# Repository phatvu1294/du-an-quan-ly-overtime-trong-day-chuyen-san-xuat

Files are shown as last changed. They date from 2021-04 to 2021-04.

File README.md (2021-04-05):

# Dự án quản lý overtime trong dây truyền sản xuất
*Dự án quản lý overtime trong dây truyền sản xuất được phát triển trên LoRa, ESP32, Arduino và C# Winform*

### Giới thiệu
Đây là bản demo cho hệ thống quản lý overtime trong dây chuyền sản xuất để đánh giá hiệu quả công việc của từng line sản xuất.
Bản demo được thiết kế trên EAGLE với mạch một lớp, không tối ưu cho bảng mạch, để áp dụng trong thương mại vui lòng liên hệ tác giả.

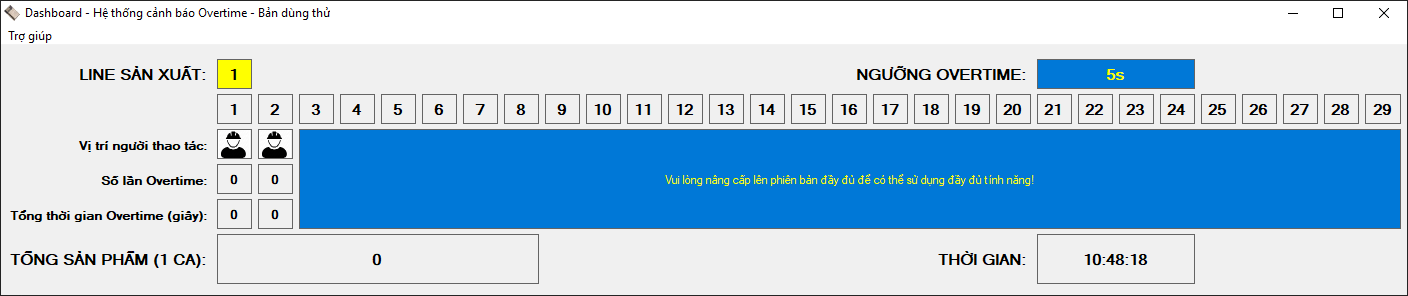
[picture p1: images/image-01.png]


### Mô tả hệ thống

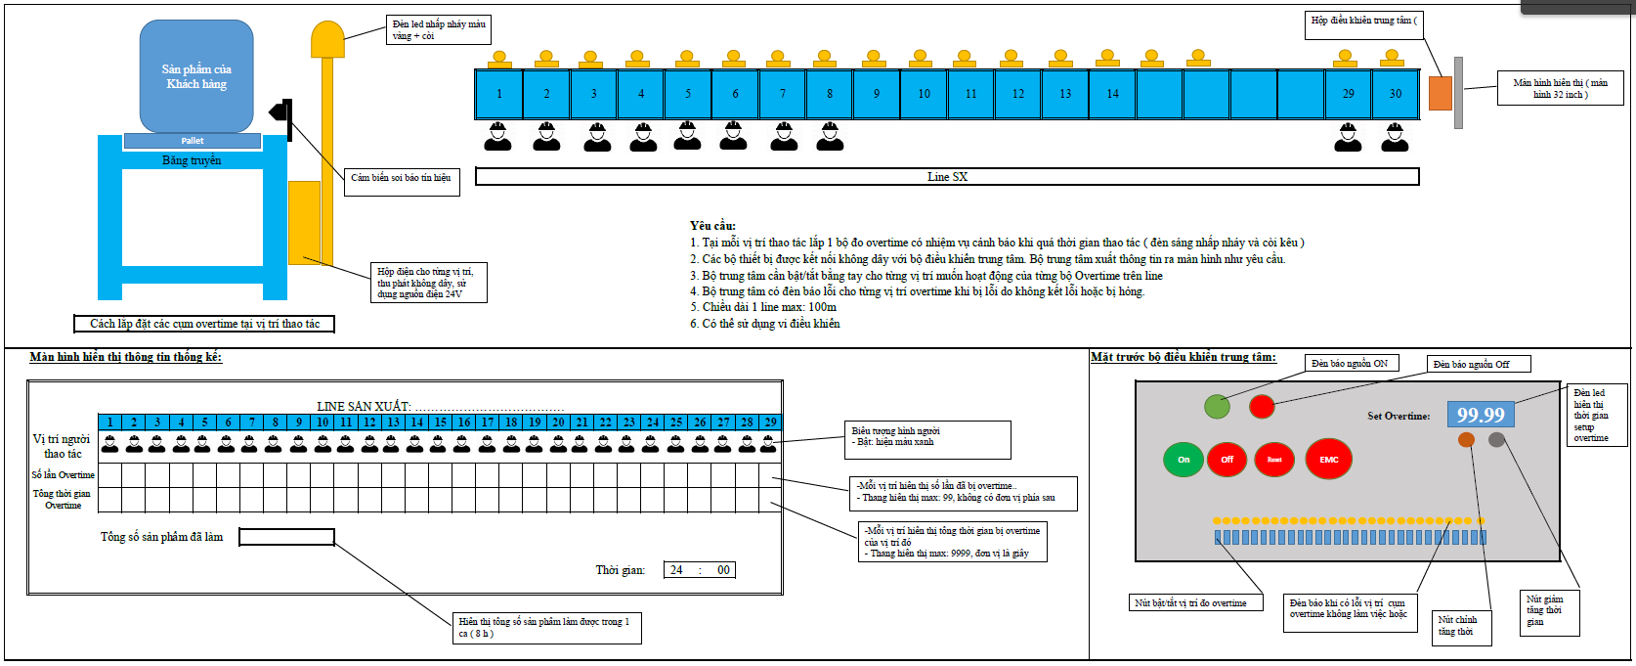
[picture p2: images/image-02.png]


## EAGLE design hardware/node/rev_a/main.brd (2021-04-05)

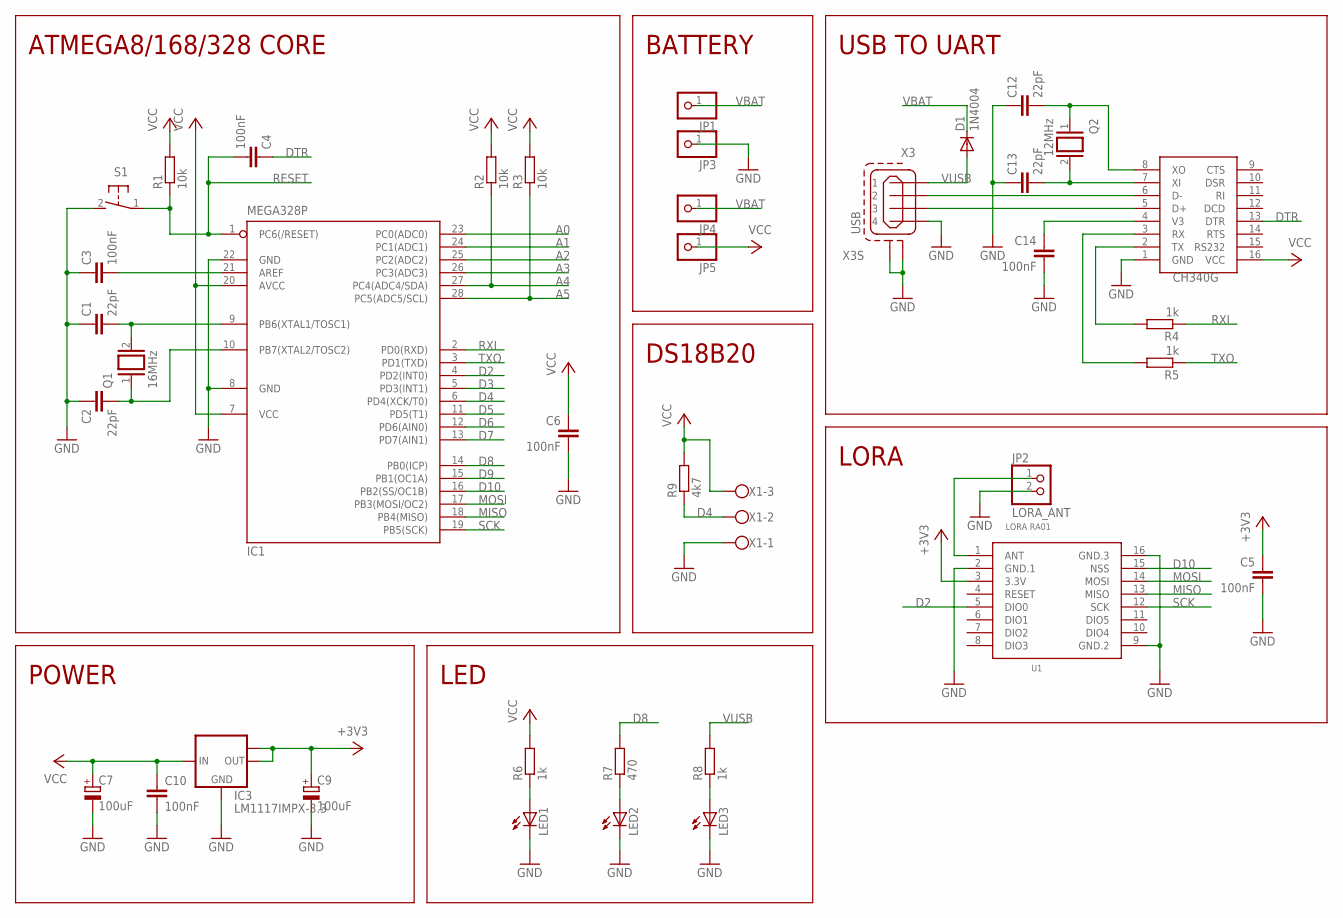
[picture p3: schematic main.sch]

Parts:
C1, C2, C12, C13: 22pF; C050-024X044
C3, C4, C5, C6, C10, C14: 100nF; C050-024X044
C7: 100uF; E3,5-10
C9: 100uF; E3,5-8
D1: 1N4004; DO41-10
IC1: MEGA328P; DIL28-3
IC3: LM1117IMPX-3.3; SOT223
JP1, JP3, JP4, JP5: PINHD-1X1; 1X01
JP2: LORA_ANT; 1X02
LED1, LED2, LED3: LED3MM
Q1: 16MHz; QS
Q2: 12MHz; QS
R1, R2, R3: 10k; 0207/10
R4, R5, R6, R8: 1k; 0207/10
R7: 470; 0207/10
R9: 4k7; 0207/10
S1: 31-XX; B3F-31XX
U1: LORA RA01; LORA-RA1-SMD
U$1: CH340G; SOIC16
X1: W237-103
X3: USB; 85-32004-00X

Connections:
+3V3: C5.1, C9.+, IC3.2 (OUT), IC3.TAB (OUT1), U1.3 (3.3V)
A0: IC1.23 (PC0(ADC0))
A1: IC1.24 (PC1(ADC1))
A2: IC1.25 (PC2(ADC2))
A3: IC1.26 (PC3(ADC3))
A4: IC1.27 (PC4(ADC4/SDA)), R2.1
A5: IC1.28 (PC5(ADC5/SCL)), R3.1
D2: IC1.4 (PD2(INT0)), U1.5 (DIO0)
D3: IC1.5 (PD3(INT1))
D4: IC1.6 (PD4(XCK/T0)), R9.1, X1.2
D5: IC1.11 (PD5(T1))
D6: IC1.12 (PD6(AIN0))
D7: IC1.13 (PD7(AIN1))
D8: IC1.14 (PB0(ICP)), R7.2
D9: IC1.15 (PB1(OC1A))
D10: IC1.16 (PB2(SS/OC1B)), U1.15 (NSS)
DTR: C4.1, U$1.13 (DTR)
GND: C1.1, C2.1, C3.1, C5.2, C6.2, C7.-, C9.-, C10.2, C12.1, C13.1, C14.2, IC1.8 (GND), IC1.22 (GND), IC3.1 (GND), JP2.2, JP3.1, LED1.K (C), LED2.K (C), LED3.K (C), S1.2 (S), U1.2 (GND.1), U1.9 (GND.2), U1.16 (GND.3), U$1.1 (GND), X1.1, X3.4, X3.M1 (S1), X3.M2 (S2)
MISO: IC1.18 (PB4(MISO)), U1.13 (MISO)
MOSI: IC1.17 (PB3(MOSI/OC2)), U1.14 (MOSI)
unnamed: JP2.1, U1.1 (ANT)
unnamed: LED3.A, R8.1
unnamed: U$1.6 (D-), X3.2
unnamed: C1.2, IC1.9 (PB6(XTAL1/TOSC1)), Q1.2
unnamed: C2.2, IC1.10 (PB7(XTAL2/TOSC2)), Q1.1
unnamed: C3.2, IC1.21 (AREF)
unnamed: LED1.A, R6.1
unnamed: LED2.A, R7.1
unnamed: U$1.5 (D+), X3.3
unnamed: C12.2, Q2.1, U$1.8 (XO)
unnamed: C13.2, Q2.2, U$1.7 (XI)
unnamed: C14.1, U$1.4 (V3)
unnamed: R5.2, U$1.3 (RX)
unnamed: R4.2, U$1.2 (TX)
RESET: C4.2, IC1.1 (PC6(/RESET)), R1.1, S1.1
RXI: IC1.2 (PD0(RXD)), R4.1
SCK: IC1.19 (PB5(SCK)), U1.12 (SCK)
TXO: IC1.3 (PD1(TXD)), R5.1
VBAT: D1.C, JP1.1, JP4.1
VCC: C6.1, C7.+, C10.1, IC1.7 (VCC), IC1.20 (AVCC), IC3.3 (IN), JP5.1, R1.2, R2.2, R3.2, R6.2, R9.2, U$1.16 (VCC), X1.3
VUSB: D1.A, R8.2, X3.1

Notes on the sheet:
LORA
ATMEGA8/168/328 CORE
USB TO UART
POWER
LED
BATTERY
DS18B20

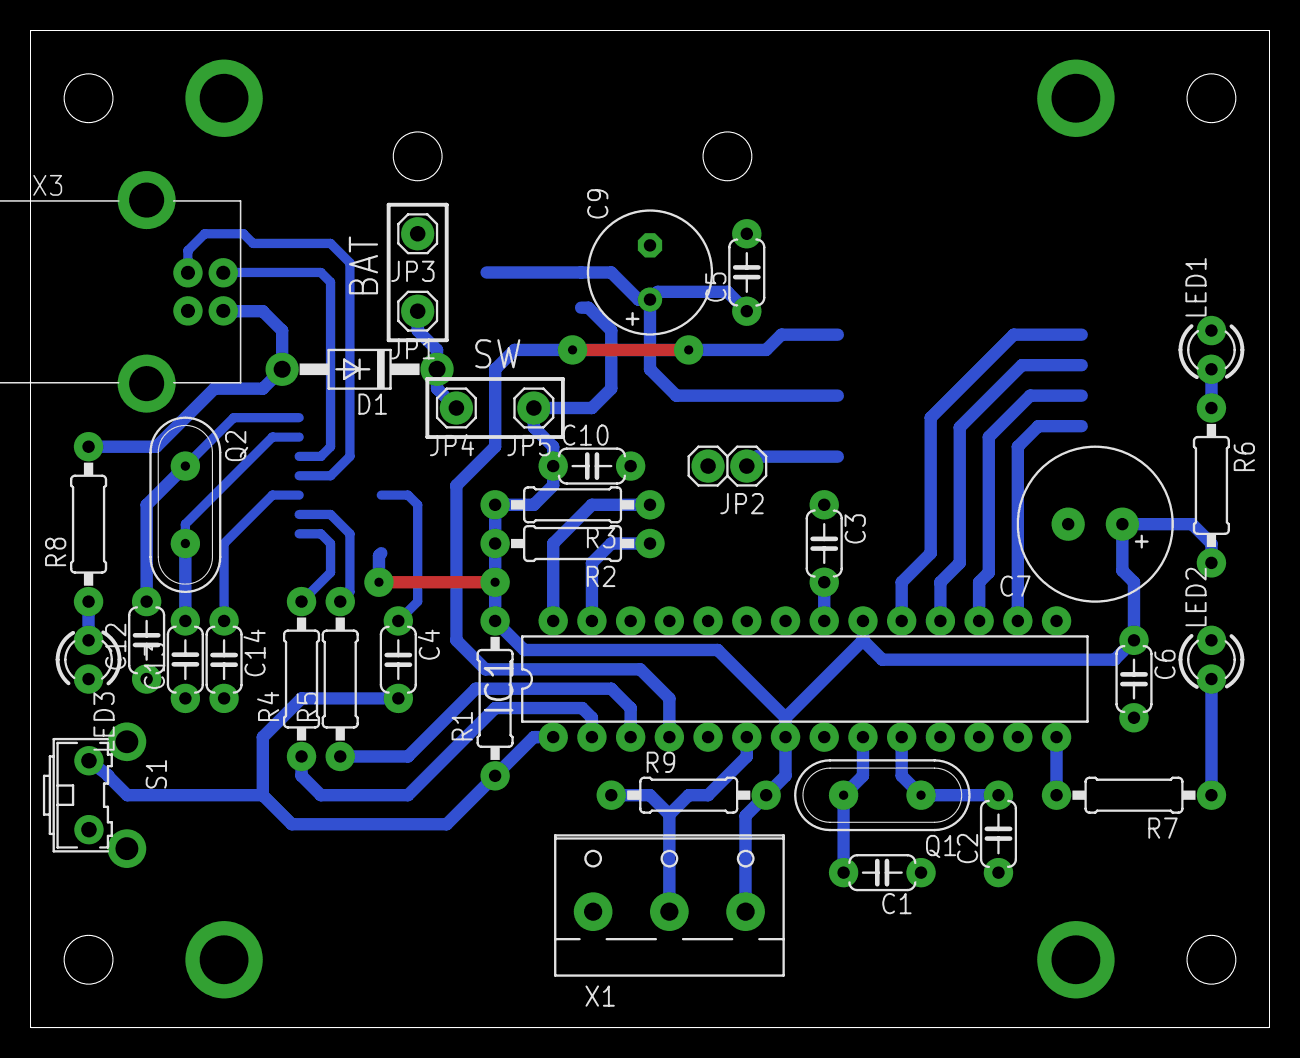
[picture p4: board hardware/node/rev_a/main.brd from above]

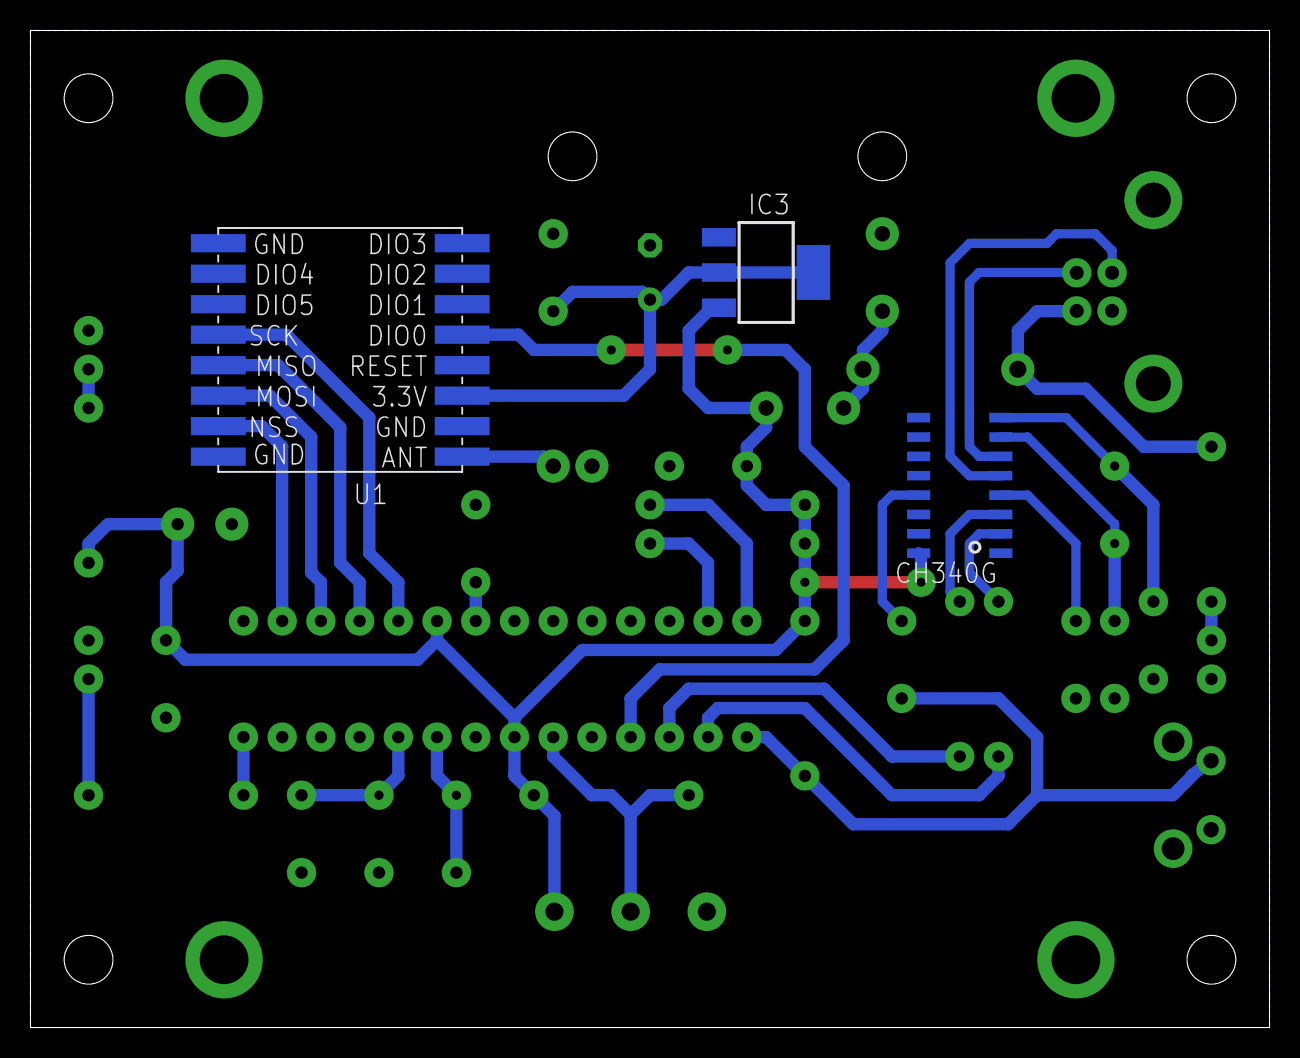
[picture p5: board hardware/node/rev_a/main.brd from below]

Board: 2 copper layers, 81.3 x 65.4 mm, 39 parts (3 on the bottom side), 32 nets.

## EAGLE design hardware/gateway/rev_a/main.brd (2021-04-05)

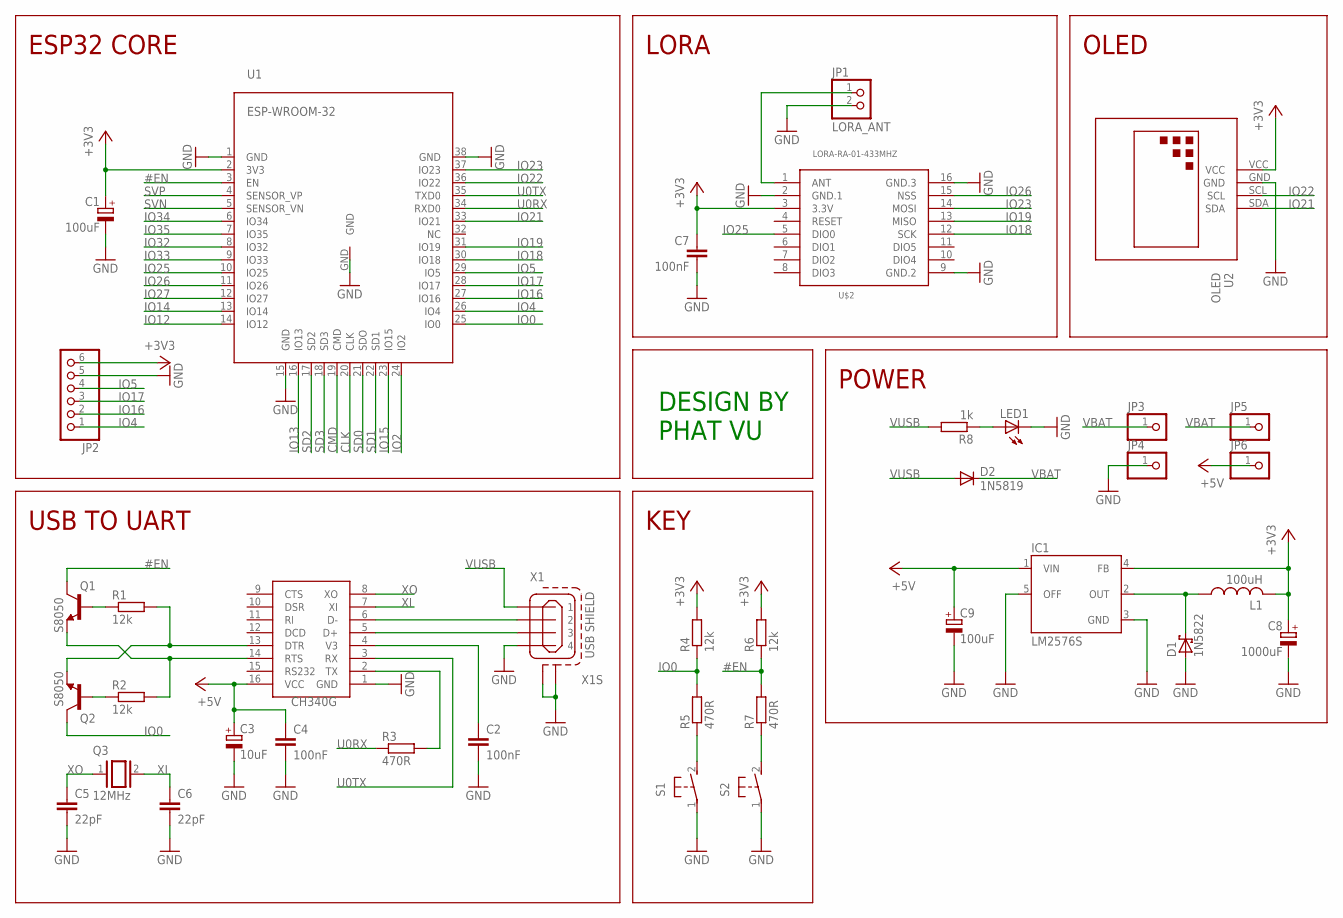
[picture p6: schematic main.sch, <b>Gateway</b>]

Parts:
C1, C9: 100uF; E5-10,5
C2, C4, C7: 100nF; C050-024X044
C3: 10uF; E2,5-6
C5, C6: 22pF; C050-024X044
C8: 1000uF; E5-13
D1: 1N5822; DO201T15
D2: 1N5819; DO41-10
IC1: LM2576S; TO263-5
JP1: LORA_ANT; 1X02
JP2: PINHD-1X6; 1X06
JP3, JP4, JP5, JP6: PINHD-1X1; 1X01
L1: 100uH; 6000-XXXX-RC
LED1: LED3MM
Q1, Q2: S8050; TO92-EBC
Q3: 12MHz; QS
R1, R2, R4, R6: 12k; 0207/10
R3, R5, R7: 470R; 0207/10
R8: 1k; 0207/10
S1, S2: 31-XX; B3F-31XX
U1: ESP-WROOM-32
U2: OLED; OLED-096-I2C
U$1: CH340G; SOIC16
U$2: LORA-RA-01-433MHZ; LORA-RA1-SMD
X1: USB SHIELD; 85-32004-00X

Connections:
#EN: Q1.C, R6.1, R7.2, U1.3 (EN)
+3V3: C1.+, C7.1, C8.+, IC1.4 (FB), JP2.6, L1.2, R4.2, R6.2, U1.2 (3V3), U2.VCC, U$2.3 (3.3V)
+5V: C3.+, C4.1, C9.+, IC1.1 (VIN), JP6.1, U$1.16 (VCC)
CLK: U1.20 (CLK)
CMD: U1.19 (CMD)
GND: C1.-, C2.2, C3.-, C4.2, C5.2, C6.2, C7.2, C8.-, C9.-, D1.A, IC1.3 (GND), IC1.5 (OFF), JP1.2, JP2.5, JP4.1, LED1.K (C), S1.1, S2.1, U1.1 (GND), U1.15 (GND), U1.38 (GND), U1.GND, U2.GND, U$1.1 (GND), U$2.2 (GND.1), U$2.9 (GND.2), U$2.16 (GND.3), X1.4, X1.M1 (S1), X1.M2 (S2)
IO0: Q2.C, R4.1, R5.2, U1.25 (IO0)
IO2: U1.24 (IO2)
IO4: JP2.1, U1.26 (IO4)
IO5: JP2.4, U1.29 (IO5)
IO12: U1.14 (IO12)
IO13: U1.16 (IO13)
IO14: U1.13 (IO14)
IO15: U1.23 (IO15)
IO16: JP2.2, U1.27 (IO16)
IO17: JP2.3, U1.28 (IO17)
IO18: U1.30 (IO18), U$2.12 (SCK)
IO19: U1.31 (IO19), U$2.13 (MISO)
IO21: U1.33 (IO21), U2.SDA
IO22: U1.36 (IO22), U2.SCL
IO23: U1.37 (IO23), U$2.14 (MOSI)
IO25: U1.10 (IO25), U$2.5 (DIO0)
IO26: U1.11 (IO26), U$2.15 (NSS)
IO27: U1.12 (IO27)
IO32: U1.8 (IO32)
IO33: U1.9 (IO33)
IO34: U1.6 (IO34)
IO35: U1.7 (IO35)
unnamed: JP1.1, U$2.1 (ANT)
unnamed: R3.2, U$1.2 (TX)
unnamed: U$1.6 (D-), X1.2
unnamed: U$1.5 (D+), X1.3
unnamed: C2.1, U$1.4 (V3)
unnamed: Q1.E, R2.2, U$1.14 (RTS)
unnamed: Q2.E, R1.2, U$1.13 (DTR)
unnamed: LED1.A, R8.1
unnamed: Q2.B, R2.1
unnamed: Q1.B, R1.1
unnamed: R7.1, S2.2 (S)
unnamed: R5.1, S1.2 (S)
unnamed: D1.C, IC1.2 (OUT), L1.1
SD0: U1.21 (SDO)
SD1: U1.22 (SD1)
SD2: U1.17 (SD2)
SD3: U1.18 (SD3)
SVN: U1.5 (SENSOR_VN)
SVP: U1.4 (SENSOR_VP)
U0RX: R3.1, U1.34 (RXD0)
U0TX: U1.35 (TXD0), U$1.3 (RX)
VBAT: D2.C, JP3.1, JP5.1
VUSB: D2.A, R8.2, X1.1
XI: C6.1, Q3.2, U$1.7 (XI)
XO: C5.1, Q3.1, U$1.8 (XO)

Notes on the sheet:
ESP32 CORE
USB TO UART
KEY
LORA
OLED
POWER
DESIGN BY PHAT VU

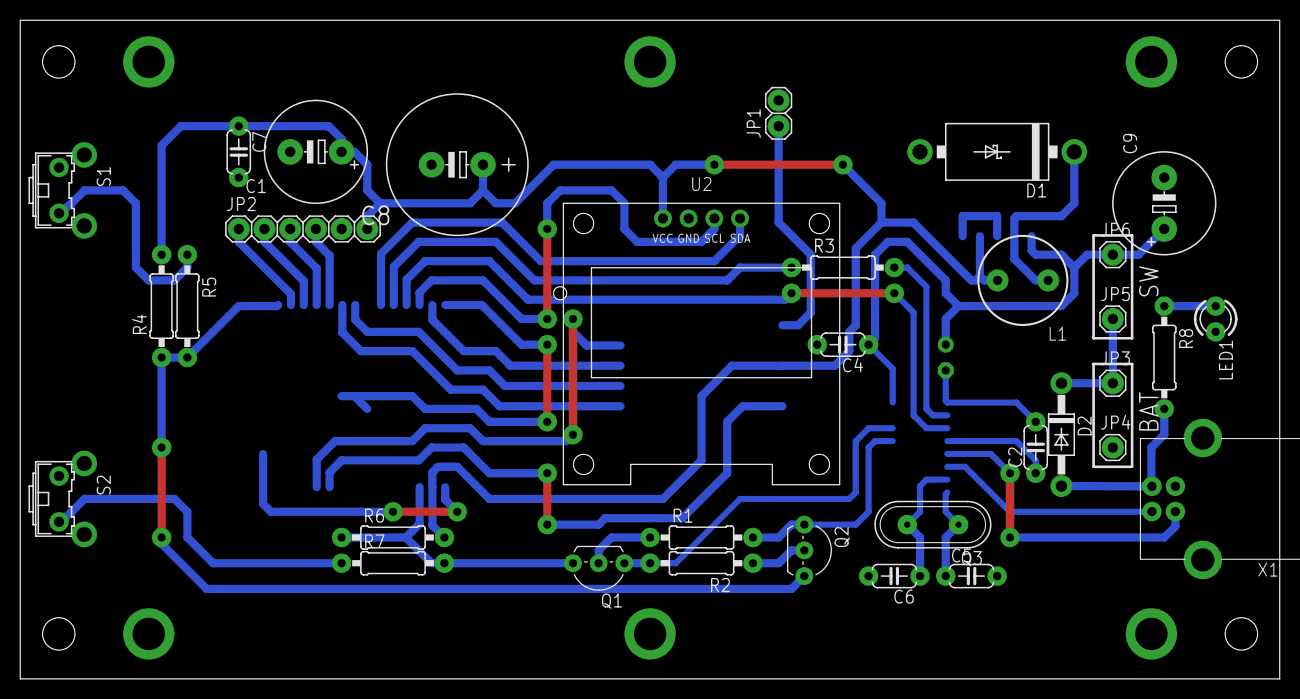
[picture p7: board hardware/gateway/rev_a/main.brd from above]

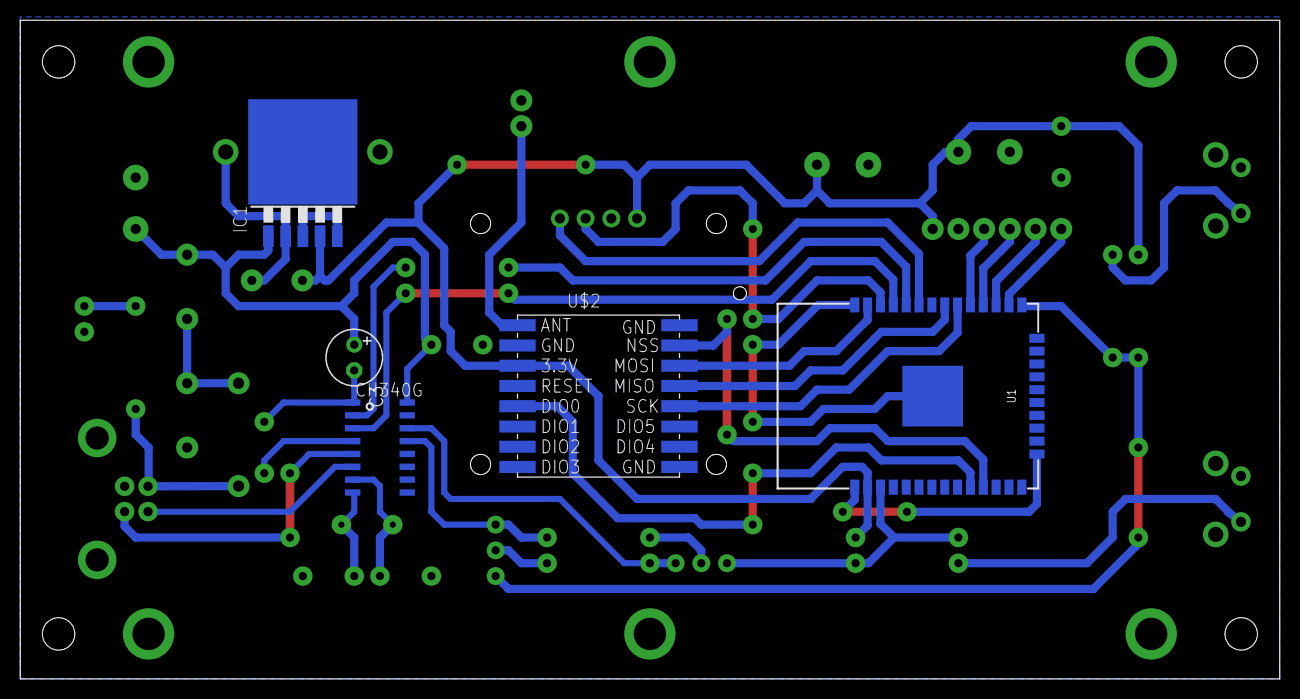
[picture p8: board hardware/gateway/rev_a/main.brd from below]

Board: 2 copper layers, 124.4 x 65.1 mm, 38 parts (5 on the bottom side), 35 nets.
